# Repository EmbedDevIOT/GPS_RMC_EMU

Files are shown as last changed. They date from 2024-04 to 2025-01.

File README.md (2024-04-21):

<div id="body" align="center">
 <h1> Эмулятор GPS RMC посылки. </h1>
 
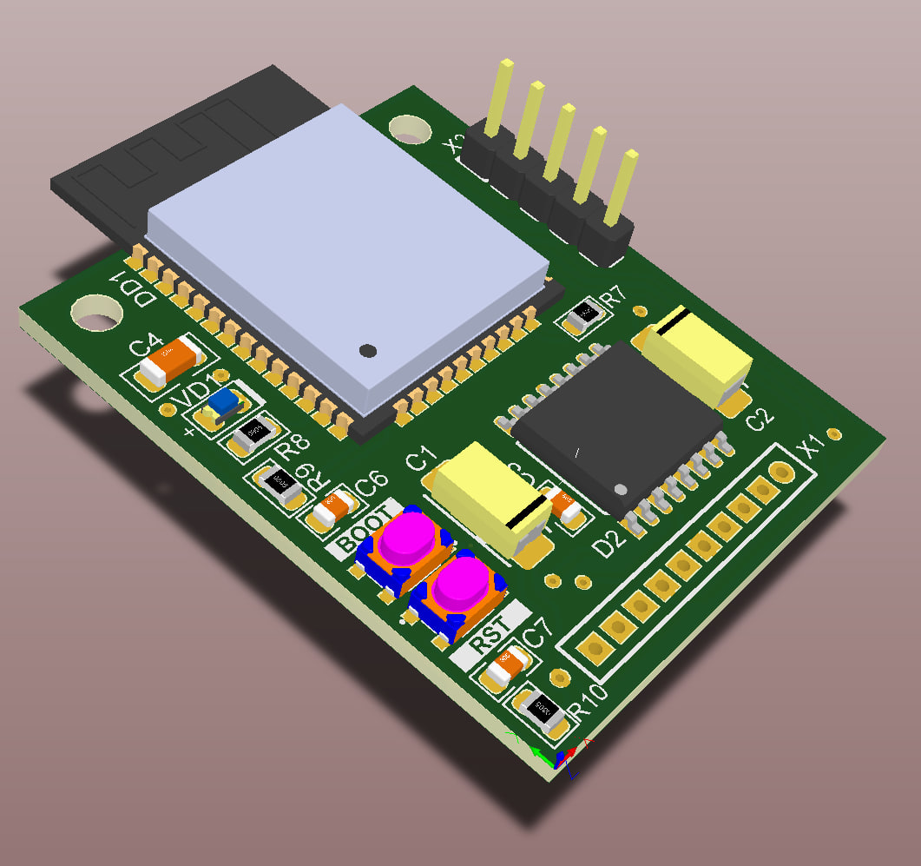
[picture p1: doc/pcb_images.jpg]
table


</div>

<p align="left">
  C
  C++
</p>

<!-- ## Used Languages  -->
* C and C++
* HTML / CSS
* JavaScript  

## Software:
VSCode&nbsp;
Platformio&nbsp;
Bootstrap5&nbsp;

* Visual Studio Code
* PlatformIO
* Arduino Framework
* Bootstrap Framework

## HARDWARE
- MCU SoC Espressif (WROOM-32D)
- DBG port
- Analog INPUT (Light Sensor)
- RTC DS3231
- Battery CR2032
- GPS / Glonass Tranmitted
- State led indicators
- User Button
  
<details>
<summary>На борту</summary>
  
  1. Wi-Fi
  2. HTTP - Server
  3. OTA - UPDATE
  4. RS-282
  </details>

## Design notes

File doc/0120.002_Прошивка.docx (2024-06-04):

## Руководство по загрузке программного обеспечения

## изделия 0120.002 rev.0 «Эмулятор GPS сигнала»


Подготовка к загрузке ПО через USB – UART TTL CP2101.

Для того чтобы загрузить прошивку в SoC или микроконтроллера DD1 Вам понадобятся следующие инструменты:

- USB-UART TTL преобразователь на CP2102.
- Провод USB-A – microUSB.
- Плата-адаптер с пружинными контактами.
- Соединительный кабель.
- ПО и драйвера необходимые для загрузки.
- Актуальная прошивка для SoC.

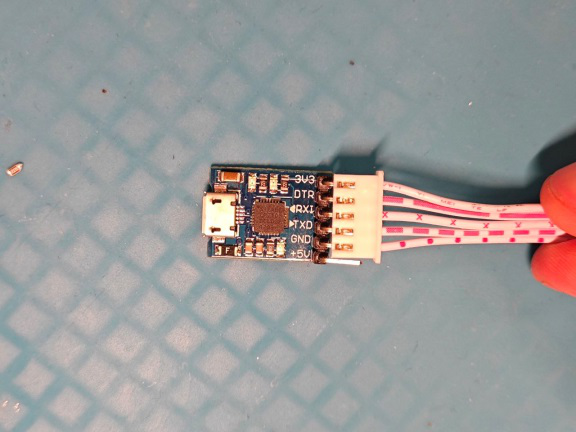
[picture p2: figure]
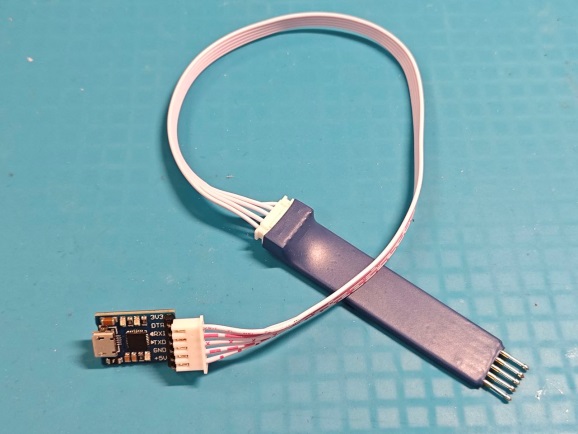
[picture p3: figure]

Подключите плату-адаптер к USB – UART преобразователю при помощи соединительного кабеля, как показано на рисунке 1.

Рисунок 1 «Соединение преобразователя и TTL конвертора» Рисунок 2 «Подключение линии питания»

Важно подключить 1пин кабеля к линии питания 3V3 USB – UART преобразователя, при этом линия +5V остается свободной. См. рисунок 2.

Далее для загрузки управляющей программы в память микроконтроллера устройства, необходимо скачать следующее программное обеспечение:

a. Драйвер UART преобразователя CP2102
b. ESPFlashDownloadTool (скачать) (https://www.espressif.com/sites/default/files/tools/flash_download_tool_3.9.5.zip)

После загрузки ПО, установите драйвер USB – UART и подключите USB-UART преобразователь с подготовленной для прошивки оснасткой. Устройство, должно определиться, как «Silicon Labs CP210x USB to UART Bridge (Ваш COM порт)

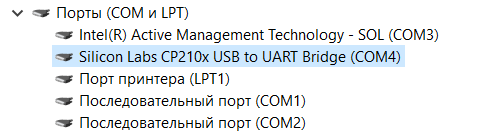
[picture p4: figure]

Если устройство не сразу не определилось системой – переподключите разъем USB или вставьте его в другой свободный разъем.

Затем запустите программу ESPFlashDownloadTool.

В стартовом окне необходимо выбрать процессор ESP32, режим Develop и запустить программу.

В открывшемся окне программы установите следующие параметры:

- SPI SPEED: 40MHz
- SPI MODE: DIO
- DoNotChqBin – check

В поле COM: выберите из списка порт преобразователя, присвоенный ранее. Например: COM4.

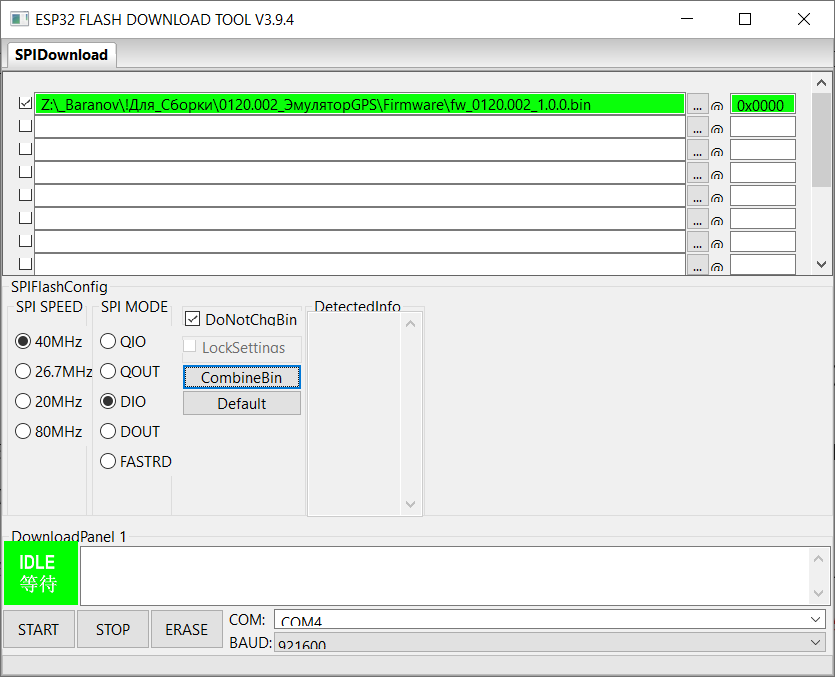
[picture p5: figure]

Рисунок 3. «Окно программы ESPFlashDownloadTool»

Данная версия прошивки является комбинированной и не требует отдельной разметки под конкретную область.

Файл прошивки имеет следующее название:

fw_0120.001_1.0.0.bin

Актуальная версия прошивки для микроконтроллера находится по адресу:

обмен\_Baranov\!Для_Сборки\0120.002_ЭмуляторGPS\Firmware

Активируем загрузку файла прошивки, установив слева галочку напротив поля «выбора загрузочного файла».

Рисунок 4. «Поля ввода ESPFlashDownloadTool»

При помощи кнопки выбора (кнопка с тремя точками «…») выбираем файл прошивки. Убеждаемся, что в поле выбора указан корректный путь.

Установим начальный адрес загрузки: 0x0000.

На этом подготовка и настройка программного обеспечения на ПК окончена, далее следует оставить окно приложение открытым и перейти к подключению адаптера.

В случае возникновения сбоев в работе ПО FlashDownloadTool – рекомендуется закрыть программу, отключить USB – UART адаптер и подключить обратно.

Подключение целевого устройства к USB – UART TTL CP2101.

Подключите программируемую плату к USB-UART преобразователю с помощью платы-адаптера, для этого необходимо убедиться в правильности соединения.

Первый контакт разъема Х2 «DBG» соответствует линии питания 3V3. Порядок расположения следующих контактов, полностью соответствует распиновке разъема USB-UART конвертора.

Вариант соединения представлен на рисунке 5.

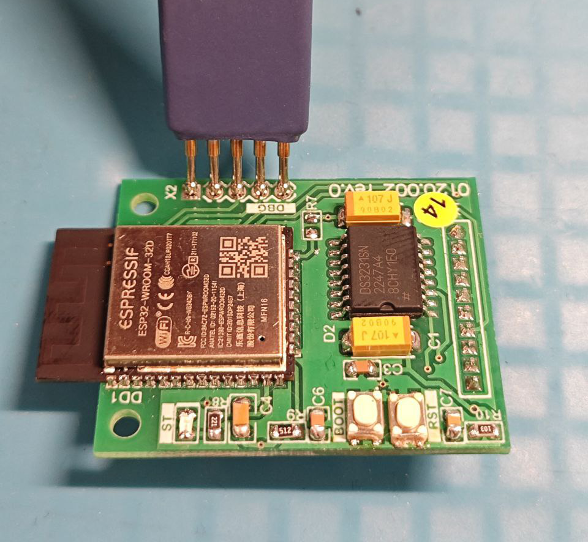
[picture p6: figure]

Рисунок 5. «Подключение целевой платы к USB-UART преобразователю».

Важно обеспечить надежный контакт всех пружинных контактов платы адаптера!

Описанные далее действия по работе с внутренней памятью микроконтроллера (очистка и загрузка) предполагают, заведомо исправное и надежное соединение целевой платы и преобразователя.

В случае возникновения ошибок при программировании или отсутствия связи с МК – переподключите адаптер и убедитесь в надежности соединения.

Очистка внутренней памяти и загрузка прошивки. Активация Bootloader.

ОЧИСТКА

Перед загрузкой основной прошивки, необходимо выполнить очистку внутренней памяти процессора. Для этого необходимо:

- В окне FlashDownloadTool нажать кнопку ERASE.
- Перевести МК в режим Bootloader.

Делается это на подключенной к адаптеру плате. Нажмите «RST» и отпустите, нажмите «BOOT» и удерживайте более 3 сек и после перехода ПО в состояние «Download» кнопку BOOT можно отпустить.

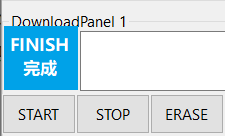
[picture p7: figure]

Статусом успешного соединения и началом работы служит переход программы в режим «Download».

Удерживаем адаптер подключенным до тех пор, пока программа не перейдет из режима «Download» в состояние «FINISH».

Дождавшись завершения процесса очистки, можно переходить к загрузке ПО.

Если в статусном окне вы увидите надпись «FAIL» это говорит о том, что микроконтроллер не вышел на связь с ПК.

Типичными проблемами являются:

- Ненадежное соединение адаптер – плата.
- Неверно выбранный COM порт адаптера.
- Микроконтроллер не перешел режим «Bootloader».
- Сбой в работе FlashDownloadTool

Все это решается проверкой пунктов, описанных ранее. Вернитесь к шагам, описанным ранее, прочитайте внимательнее инструкцию и повторите действия.

ЗАГРУЗКА ПРОШИВКИ

- В окне FlashDownloadTool нажать кнопку START.
- Перевести МК в режим Bootloader (см. выше).

Процесс загрузки будет отображен в «прогресс баре» панели загрузки. Дожидаемся окончания загрузки ПО, в случае успеха, закрываем окно и переходим к настройкам параметров (см README).

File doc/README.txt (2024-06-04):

=============== Настройка  контроллера 0120.002 "Эмулятор GPS посылки" ===========================

! Для уменьшения воздействия СВЧ WiFi передатчика а усилительный тракт устройства, WiFi имеет встроенный 
таймер работы и доступен первые 5 минут после включения устройства, затем отключается.
Короткие вспышки индикатора ST информируют пользователя о том что WiFi активен.

1. Подключиться к WiFi сети устройства
	1.1 Вкл. WiFi на вашем устройстве.
	1.2 Дождаться обновления списка доступных сетей или принудительно обновить список.
	1.3 Выбрать из списка сеть с именем: 0120-0 и подключиться к ней.
	1.4 Пароль: retra0120zxc

	1.5* Если подключение производится с мобильного устройства, дождаться всплывающего сообщения
		что данная сеть не имеет доступа к интернету и принять его.
	1.6* Если Вы не получили сообщение из п.1.5 или используете компьютер на базе ОС Windows,
		рекомендуется отключить стороннее подключение к интернету.
		Для мобильных устройств: Отключить мобильный интернет
		Для ПК: локальную сеть, имеющую доступ в сеть интернет.

	1.7 Перейти в Панель настройки параметров (см. п.2 "Настройка параметров")
	
	* п.1.5 и 1.6. Рекомендуется выполнить для обеспечения стабильного доступа к ресурсам усройства.

2. Настройка параметров.
	2.1 Открыть браузер на вашем усройстве.
	2.2 В строке адреса задать: 192.168.1.1 и подтвердить переход
	2.3 Откроется WiFi GUI. Панель настроек.
	2.4 В строке время / дата - установить актуальные значения 
	2.5 В текущем блоке нажать кнопку: "Сохранить параметры"
	2.6 Текущие настройки заносятся RTC и обеспечивают отсчет даты/времени
		независимо от сети питания устройства. Питание чипа RTC обеспечивает
		встроенная батарея стандарта CR2032.

3. Сервисные функции.

	3.1 Установка серийного номера:
	3.2 Подключиться к WiFi сети усройства (см.п.1)
	3.3 Открыть браузер и установить серийный номер при помощи следующей команды:
		http://192.168.1.1/SNUPD?sn=X , где X - серийный номер от 1 до 65536.**

	** Серийный номер не может принимать значения типа "строка" или значения с плавающей запятой, а 	так-же отрицательные значения. 

===================================================================================================

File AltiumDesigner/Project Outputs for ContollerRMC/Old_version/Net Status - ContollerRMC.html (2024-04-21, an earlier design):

Altium customize

# Net Status Report

Date: | | 21.04.2024
Time: | | 15:32:44
Elapsed Time: | | 00:00:00
Filename: | | V:\Baranov\1_Work\1_Desing_documents\0120.002_EmulatorGPS_rev.0\ControllerAD\ContollerRMC.PcbDoc
Units: | | mmmils

Nets | Layer | Length
+3V3 | Signal Layers Only | 156.2476mm
BOOT | Signal Layers Only | 34.9345mm
EN/RST | Signal Layers Only | 72.7454mm
GND | Signal Layers Only | 39.4431mm
GPIO5 | Signal Layers Only | 22.0633mm
I2C_SCL | Signal Layers Only | 46.5244mm
I2C_SDA | Signal Layers Only | 42.3227mm
IO_2 | Signal Layers Only | 4.0929mm
NetD1_1 | Signal Layers Only | 3.9668mm
NetD1_2 | Signal Layers Only | 65.0449mm
NetD2_1 | Signal Layers Only | 12.9655mm
NetD2_3 | Signal Layers Only | 17.2361mm
NetR8_1 | Signal Layers Only | 2.5mm
RX0 | Signal Layers Only | 13.014mm
RX2 | Signal Layers Only | 43.4987mm
TX0 | Signal Layers Only | 11.9168mm
TX2 | Signal Layers Only | 50.248mm
VD_ST | Signal Layers Only | 4.0802mm

Back to top

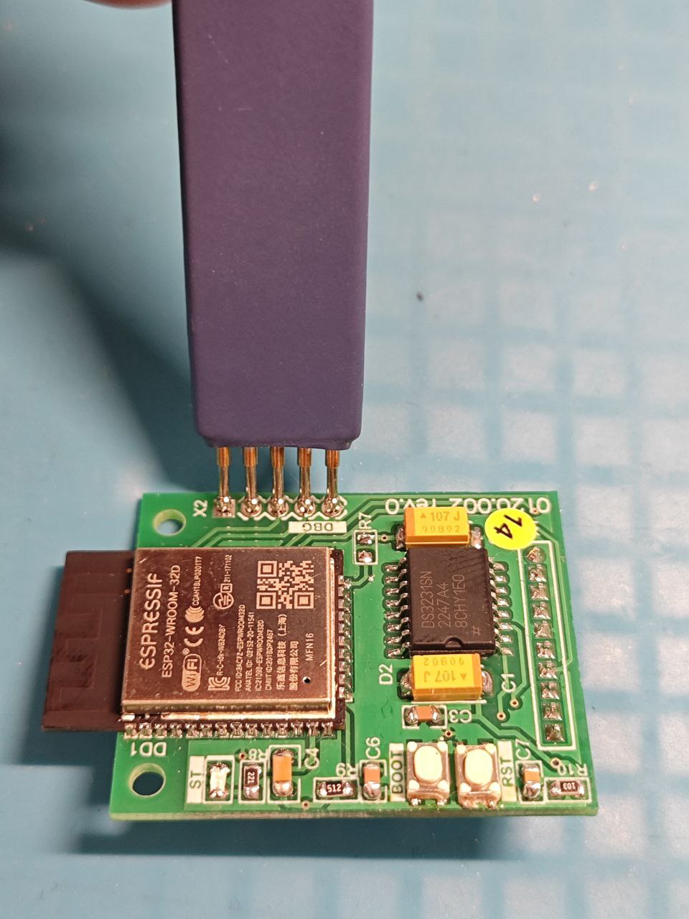
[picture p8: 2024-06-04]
doc/image/conn_to_pcb.jpg

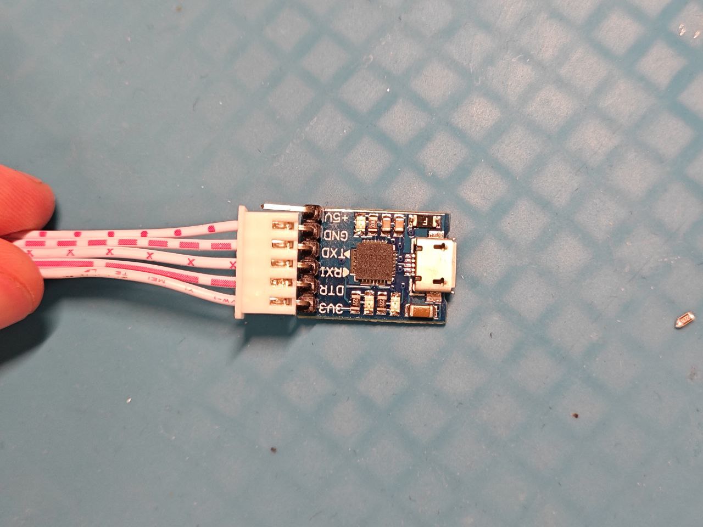
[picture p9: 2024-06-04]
doc/image/USB_TTL.jpg

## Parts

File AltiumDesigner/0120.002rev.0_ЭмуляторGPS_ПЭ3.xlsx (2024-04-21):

Позиционное обозначение | Наименование | Кол
 | Диоды
D1 | Диод Шоттки 1N5819HW 40V 1A (SOD-123) | 1
 |  |  | ! Перечень компонентов, необходимых для сборки 0120.002 rev.0 . Перечень составлен на сборку одной ПП.
 | Конденсаторы
C1, C2 | Конденсатор танталовый SMD, TECAP тип С 100 мкф х 6,3 В | 2
C3 | Конденсатор чип 0805 100 нф | 1
C4 | Конденсатор чип 1206 100 нф | 1
C6 | Конденсатор чип 0805 1 мкф | 1
C7 | Конденсатор чип 0805 10 мф | 1
 | Кнопки
SB1, SB2 (Не устанавливать) | Кнопка тактовая micro smd 3х4х2.5мм SMT G75 | 2
 | Микросхемы
DD1 | Встраиваемый Wi-Fi/Bluetooth модуль на базе чипа ESP32-D0WD с PCB-антенной. ESP32-WROOM-32D [16MB] | 1
D2 | Микросхема DS3231SN, Часы реального времени I2C, SO-16-300 | 1
 | Оптоэлектроника
VD1 | Светодиод синий или зеленый SMD 0805 | 1
 | Резисторы
R1, R8 | Чип резистор 0805 220 Ом (5%) | 2
R2, R3, R5, R6, R7 | Чип резистор 0805 4.7 кОм (5%) | 5
R4, R10 | Чип резистор 0805 10 кОм (5%) | 2
R9 | Чип резистор 0805 5 кОм (5%) | 1
 | Установочные изделия
G1 | Батарейный отсек CR2032, L-KLS5-CR2032-09B (BTH-R36-20) | 1
X1 | Вилка штыревая PLS-10 2мм 1х10pin (прямая) | 1
X2 (не устанавливать) | Вилка штыревая PLS-5 2.54мм 1х5pin (прямая) | 1
 | Батарея CR2032 | 1
 | Плата печатная 0120.002.rev.0 | 1

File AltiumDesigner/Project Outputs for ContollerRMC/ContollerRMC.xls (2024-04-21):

Comment | Description | Designator | Footprint | LibRef | Quantity
100u | TECAP, 100 мкФ, 6.3 В, тип C, 10% | C1, C2 | EL Case C (6032-28) | 100u-6.3V | 2
0.1u | SMD-0805 | C3 | C0805(2013) | C-0805 | 1
100n | SMD-1206 50V Y5V +80/-20% | C4 | C1206(3216) | C-1206 50V 100n | 1
1mf | SMD-0805 | C6 | C0805(2013) | C-0805 | 1
10uf | SMD-0805 | C7 | C0805(2013) | C-0805 | 1
1N4148WS | SOD-323 100V 150mA | D1 | SOD323 | 1N4148WS | 1
DS3231SN | I2C real-time clock (RTC) Integrated RTC/TCXO/Crystal | D2 | SO16-300 | DS3231SN | 1
ValueManufacturerPartNumber | ESP32-D0WD, Wi-Fi, BLE, 80 - 240MHz | DD1 | ESP32-WROOM-32D | ESP32 - WROOM - 32U | 1
BAT | BATTERY HOLDER COIN CR1220 | G1 | BAT: BTH-R36-20 | BATCR1220 | 1
220 | SMD 0805 0.1W 5% 150V | R1, R8 | R0805 | R-0805 | 2
4.7k | SMD 0805 0.1W 5% 150V | R2, R3, R5, R6, R7 | R0805 | R-0805 | 5
10k | SMD 0805 0.1W 5% 150V | R4, R10 | R0805 | R-0805 | 2
5k | SMD 0805 0.1W 5% 150V | R9 | R0805 | R-0805 | 1
BOOT | SMD Button, 3х4х2.5 mm, 24VDC, 50mA | S1 | BUT_SKRPACE010 | Button SMD 3х4х2.5 | 1
RST | SMD Button, 3х4х2.5 mm, 24VDC, 50mA | S2 | BUT_SKRPACE010 | Button SMD 3х4х2.5 | 1
ST | BLUE 247мКд, 120°, 468нМ | VD1 | Led 0805-Blue | Led 0805 SMD 2013. TO-2013BC-BF | 1
 |  | X1 | CON: PLS-10 - 2.0mm | 10-Connector | 1
DBG |  | X2 | CON: PLS-5 | 5-Connector | 1

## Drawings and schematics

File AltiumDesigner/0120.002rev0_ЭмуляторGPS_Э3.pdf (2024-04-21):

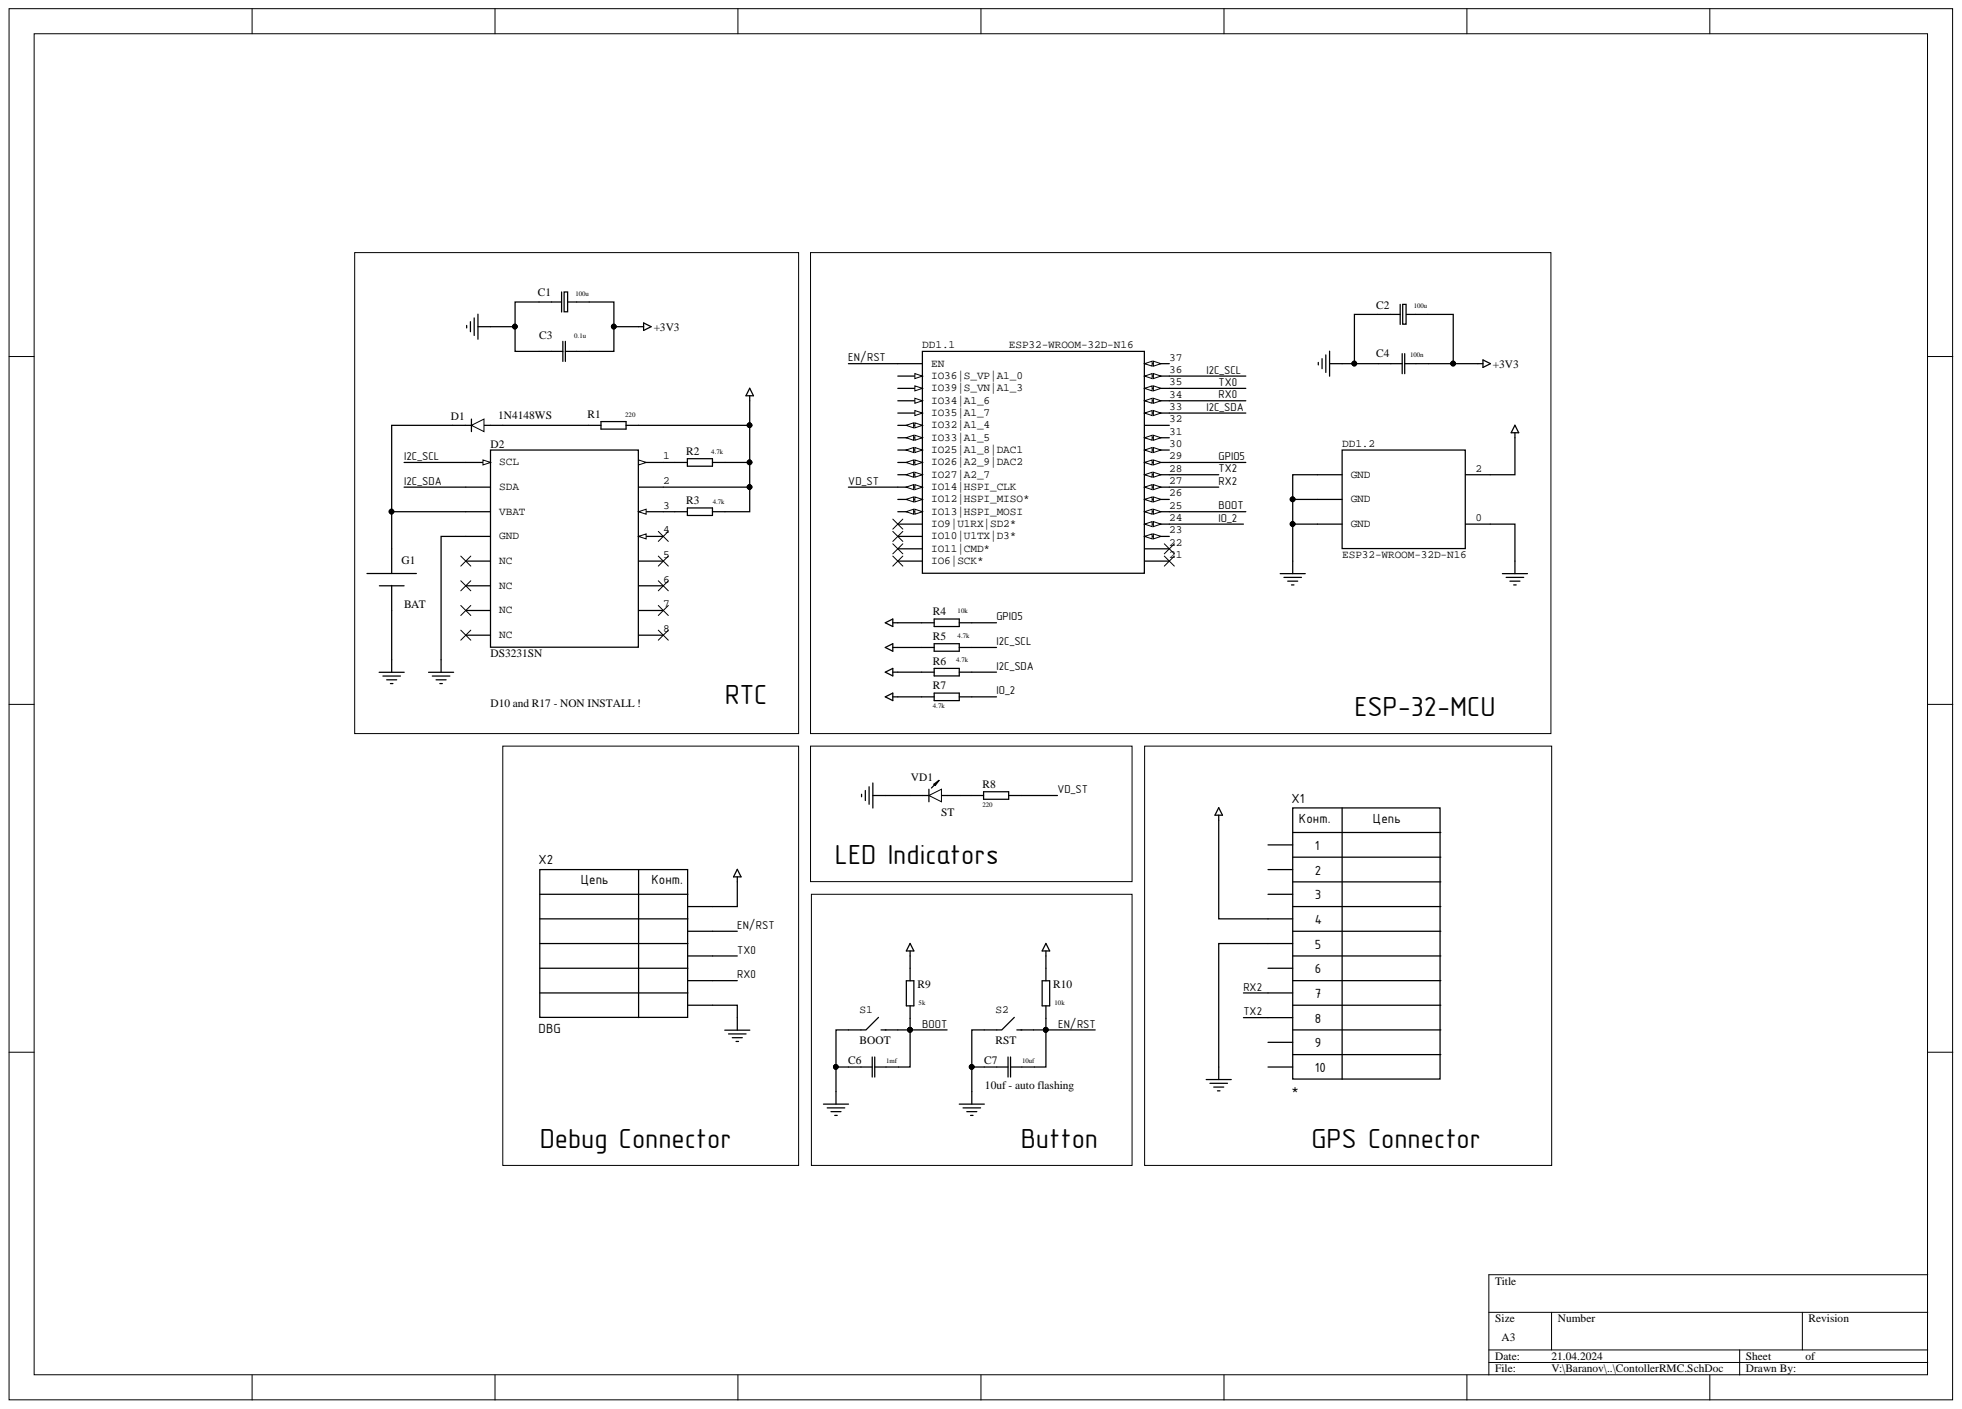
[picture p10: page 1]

Конт. | Цепь

Цепь | Конт.

Button

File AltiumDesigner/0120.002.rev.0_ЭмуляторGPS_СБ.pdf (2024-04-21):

A

## Top (Масштаб 2:1)

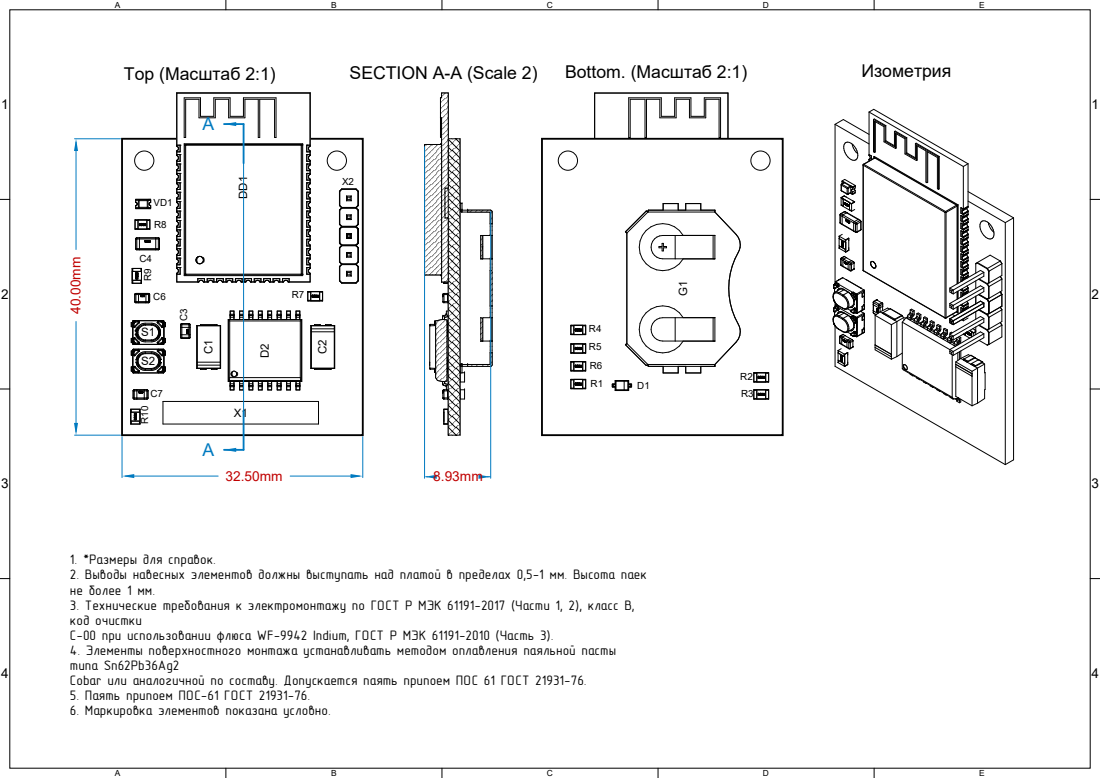
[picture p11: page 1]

1. *Размеры для справок.
2. Выводы навесных элементов должны выступать над платой в пределах 0,5-1 мм. Высота паек
не более 1 мм.
3. Технические требования к электромонтажу по ГОСТ Р МЭК 61191-2017 (Части 1, 2), класс В,
код очистки
C-00 при использовании флюса WF-9942 Indium, ГОСТ Р МЭК 61191-2010 (Часть 3).
4. Элементы поверхностного монтажа устанавливать методом оплавления паяльной пасты
типа Sn62Pb36Ag2
Cobar или аналогичной по составу. Допускается паять припоем ПОС 61 ГОСТ 21931-76.
5. Паять припоем ПОС-61 ГОСТ 21931-76.
6. Маркировка элементов показана условно.

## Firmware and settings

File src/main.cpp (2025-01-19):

#include "Config.h"

#include "FileConfig.h"
#include "WF.h"
#include "HTTP.h"

#define RX2 16
#define TX2 17


//=========================== GLOBAL VARIABLES =========================
char buf[32] = {0}; // buff for send message
// String rmc_msg = "$GPRMC,144526.539,A,5231.772,N,01324.117,E,777.4,084.4,120424,000.0,W*7C";
String rmc_msg = "";
uint8_t sec_cnt = 0;
uint8_t data = 0;
uint8_t month = 0;
uint16_t year = 0;
//======================================================================

//================================ OBJECTs =============================
MicroDS3231 RTC;
TaskHandle_t TaskCore_0;
TaskHandle_t TaskCore_1;
//=======================================================================

//============================== STRUCTURES =============================
DateTime Clock;
GlobalConfig CFG;
Flag STATE;
WiFiConfig WiFiC;
//=======================================================================

//======================    FUNCTION PROTOTYPS     ======================
void HandlerCore0(void *pvParameters);
void HandlerCore1(void *pvParameters);
void CheckWiFi(void);
//=======================================================================

//=======================================================================
// Pinned to Core 0. Network Stack Handler
void HandlerCore0(void *pvParameters)
{
    Serial.print("Task0 running on core ");
    Serial.println(xPortGetCoreID());
    for (;;)
    {
        if (STATE.WiFiEN)
            HandleClient();
        vTaskDelay(10 / portTICK_PERIOD_MS);
    }
}

// Pinned to Core 1.
void HandlerCore1(void *pvParameters)
{
    Serial.print("Task1 running on core ");
    Serial.println(xPortGetCoreID());
    for (;;)
    {
        if (STATE.WiFiEN)
            CheckWiFi();

        Clock = RTC.getTime();
        DebugInfo();

        if(CFG.GPS_MODEL == L76){
            Build_and_SendNMEA();
        }else{
            Build_and_SendNL3333();
        }         

        vTaskDelay(1000 / portTICK_PERIOD_MS);
    }
}
//=======================================================================

//=======================       S E T U P       =========================
void setup()
{
    CFG.fw = "1.1";
    CFG.fwdate = "19.01.2025";

    CFG.GPS_MODEL = NL3333;

    if(CFG.GPS_MODEL == L76){
        CFG.gps_speed = 9600;
    }else{
        CFG.gps_speed = 115200;
    }

    Serial.begin(UARTSpeed);
    Serial2.begin(CFG.gps_speed, SERIAL_8N1, TX2, RX2);

    SystemInit();
    // RTC INIT
    RTC.begin();
    // Low battery / RTC battery crash / Set time compilations
    if (RTC.lostPower())
    {
        RTC.setTime(COMPILE_TIME);
    }
    Clock = RTC.getTime();
    Serial.println(F("RTC...Done"));

    byte errSPIFFS = SPIFFS.begin(true);

    LoadConfig(); // Load configuration from config.json files

    ShowLoadJSONConfig();

    WIFIinit();

    vTaskDelay(1000 / portTICK_PERIOD_MS);

    HTTPinit(); // HTTP server initialisation
    vTaskDelay(1000 / portTICK_PERIOD_MS);

    pinMode(LED_ST, OUTPUT);
    digitalWrite(LED_ST, LOW);

    for (uint8_t i = 0; i < 5; i++)
    {
        Build_and_SendNMEA();
        vTaskDelay(1000 / portTICK_PERIOD_MS);
    }

    xTaskCreatePinnedToCore(
        HandlerCore0,
        "TaskCore_0",
        10000,
        NULL,
        1,
        &TaskCore_0,
        0);
    delay(500);

    xTaskCreatePinnedToCore(
        HandlerCore1,
        "TaskCore_1",
        2048,
        NULL,
        1,
        &TaskCore_1,
        1);
    delay(500);
}
//=======================================================================

//=======================        L O O P        =========================
void loop() {}
//=======================================================================

//=======================================================================
void CheckWiFi()
{
    STATE.Led = !STATE.Led;
    digitalWrite(LED_ST, STATE.Led);

    if (STATE.WiFiEN == true && WiFiC.Tsec < 59)
    {
        WiFiC.Tsec ++;
    }
    else
    {
        WiFiC.Tsec = 0;
        WiFiC.Tmin ++;
    }

    if (WiFiC.Tmin == 2)
    {
        STATE.Led = false;
        digitalWrite(LED_ST, STATE.Led);
        STATE.WiFiEN = false;
        Serial.println("WiFi_Disable");
        WiFi.disconnect();
        WiFi.mode(WIFI_OFF);
    }
}
//=======================================================================

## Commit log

2024-04-19 v.0.6 <19.04.24> Add AltiumDesigner
    [ContollerRMC.DRL, ContollerRMC.GBL, ContollerRMC.GBO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]
2024-04-21 AltiumDesigner update
    [0120.002rev.0_ЭмуляторGPS_ПЭ3.xlsx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]
2024-05-15 1.0 <15.05.24> UART update
